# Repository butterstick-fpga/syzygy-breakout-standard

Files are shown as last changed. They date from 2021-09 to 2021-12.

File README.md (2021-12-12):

# SYZYGY breakout

SYZYGY is an FPGA expansion standard for medium to high speed interfaces. Learn more and check out the specifications here: [https://syzygyfpga.io/](https://syzygyfpga.io/)

> Note that the attiny44A populated on boards from the GroupGets campaign are delivered blank.

---

## What is it

- A breakout with all 32 I/O pins broken out to a 0.1" header. 
- A small prototyping area is also provided.
- attiny44a provided to enable SYZYGY DNA features.

## Photos

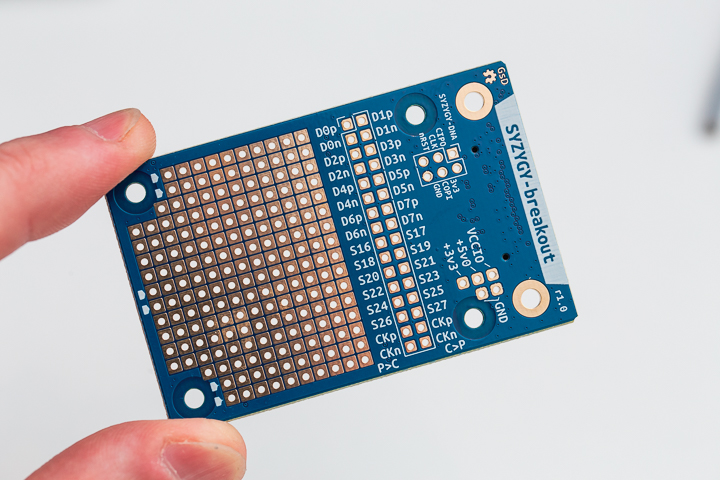
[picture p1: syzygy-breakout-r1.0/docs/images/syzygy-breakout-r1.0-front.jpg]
Front
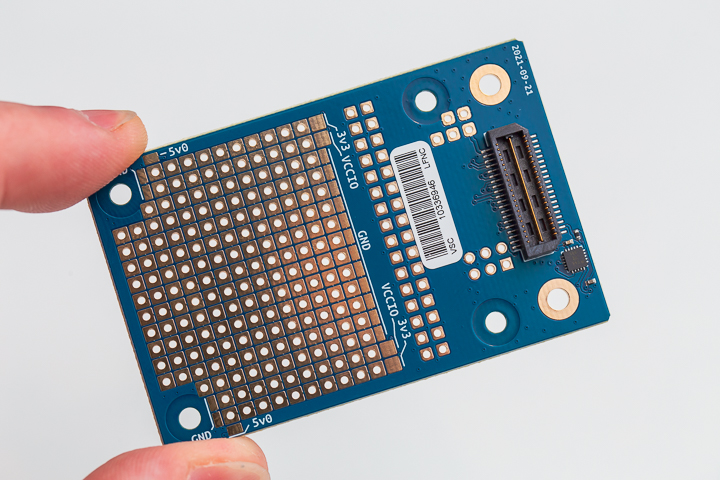
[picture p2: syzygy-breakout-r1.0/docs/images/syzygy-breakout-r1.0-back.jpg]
Back
 

## Prototyping area

The prototyping area is set up like a traditional breadboard layout, if you examine the back of the board you can see tracks that run between the 0.1" prototyping holes.
You can also see these details in the KiCad design files.

Available on the back of the board is various power rails that are available to "jumper" across to the prototyping area.

## Attiny44A Firmware

The attiny44A is fitted to provide SYZYGY DNA features, a mechanism that SYZYGY controllers can poll to determine what pods are connected, and their VCCIO range etc.

Currently, the firmware for this hasn't been developed/tested yet. This feature also requires the controller (E.g. ButterStick) to have a mechanism to poll the pods for this info.

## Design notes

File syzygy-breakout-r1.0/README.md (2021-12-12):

# SYZYGY breakout

SYZYGY is an FPGA expansion standard for medium to high speed interfaces. Learn more and check out the specifications here: [https://syzygyfpga.io/](https://syzygyfpga.io/)

---

## What is it

A breakout with all 32 I/O pins broken out to a 0.1" header. 

A small prototyping area is also provided.

## Folder structure

```
kicad-src: KiCad v6 source files
production:
 - Gerbers:      [project]_gerbers.zip
 - Schematic:    [project].pdf
 - Board render: [project].png
```

## Photos

Front Back

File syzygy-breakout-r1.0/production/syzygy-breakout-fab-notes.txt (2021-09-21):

Part number:        syzygy-breakout-r1.0

General fabrication notes

    * Board material is S1000-2
    * Blue solder mask on both sides of board. All vias to be tented.
    * White LPI legend on both sides of board.
    * Pad finish is ENIG.
    * Finished board thickness is 1.6 mm
    * Broads in panel. Arrangement TBD, using routing/tabs/v-score.
    
Suggested stackup
    1   35 μm (1 oz) copper         Signal
        0.2mm prepreg
    2   17 μm (0.5 oz) copper       Signal
        Select core/prepreg for final board thickness
    3   17 μm (0.5 oz) copper       Ground
        0.2mm prepreg
    4   35 μm (1 oz) copper         Signal

File naming
    syzygy-breakout-Edge_Cuts.gbr        Board outline
    syzygy-breakout-PTH.drl              Through-board plated holes
    syzygy-breakout-NPTH.drl             Through-board unplated holes
    syzygy-breakout-F_SilkS.gbr          Front silkscreen
    syzygy-breakout-F_Mask.gbr           Front solder mask
    syzygy-breakout-F_Cu.gbr             Layer 1 copper (Front)
    syzygy-breakout-In1_Cu.gbr           Layer 2 copper
    syzygy-breakout-In2_Cu.gbr           Layer 3 copper
    syzygy-breakout-B_Cu.gbr             Layer 4 copper (Back)
    syzygy-breakout-B_Mask.gbr           Back solder mask
    syzygy-breakout-B_SilkS.gbr          Back silkscreen

    syzygy-breakout-PTH-drl_map.pdf      Drill Map Reference plated
    syzygy-breakout-NPTH-drl_map.pdf     Drill Map Reference non-plated

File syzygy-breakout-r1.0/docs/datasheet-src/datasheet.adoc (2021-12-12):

= SYZYGY Pod
:imagesdir: ../images
:source-highlighter: rouge
:bl: pass:[ +]
:toc: macro
:icons: font

_Standard Breakout_

'''

== General Description
The SYZYGY Standard Breakout is an addon board for carriers following the SYZYGY FPGA standard.

The POD features the SYZYGY Stardard connector that enables 32 single ended I/O or 10 differential pairs. It also features a small ATTiny44 microcontroller, that can be used to implement SYZYGY-DNA features.

All SYZYGY I/O signals are routed into a 0.1" labeled dual-row header, From here connections can be made directly or jumped over onto the prototyping area on the PCB. Breakouts are also offered for the ATTiny ICSP interface, and voltages from the carrier.

'''

[cols=2,frame=none,grid=none]
|===
a|
[#_anchor]
== Key features:
  * Compact Size
  * All I/O broken out
  * Universial prototyping area

SYZYGY Breakout Front

a|
== Specifications:
  * All 32 SYZYGY-STD I/O broken out
  * All power rail broken out
  * Multiple power configurations
  * SYZYGY-DNA I2C bus accessable
  * Lots of prototyping space
  * Open source KiCad Design
  * Dimensions: 45.0mm x 70.0mm (1.8" x 2.8")
|===

{bl}
{bl}

== Product Variants

[cols="1,2",frame=ends, grid=cols]
|===
|Part Number|Description

|SYZYGY-STD-R1D0
|Populated PCBA, unprogrammed.

|SYZYGY-STD-R1D0-BARE
|Bare PCB

|===

<<<

== Licence
 - Hardware: https://spdx.org/licenses/CERN-OHL-P-2.0.html[CERN-OHL-P-2.0]
 - Documentation: https://spdx.org/licenses/CC-BY-SA-4.0.html[CC-BY-SA-4.0]

{bl}
{bl}

== Revision History

[cols="^1,^1,6",frame=ends, grid=cols]
|===
|Revision|Date|Description

|r1d0|2021-12-12|Initial Release

|===

{bl}
{bl}

toc::[]

<<<

== Images

.Top of PCB
SYZYGY Breakout Front

.Bottom Of PCB 
[SYZYGY Breakout Back

<<<

{bl}

== Pinout

[cols="^1,2,^1,2",width=50%,align=center,frame=all, grid=cols, stripes=even]
|===
|Pin|Signal Name|Pin|Signal Name

|`1`  | `S0 D0p`  |  `2`  | `S1 D1p`
|`3`  | `S2 D0n`  |  `4`  | `S3 D1n`
|`5`  | `S4 D2p`  |  `6`  | `S5 D3p`
|`7`  | `S6 D2n`  |  `8`  | `S7 D3n`
|`9`  | `S8 D4p`  |  `10` | `S9 D5p`
|`11` | `S10 D4n` |  `12` | `S11 D5n` 
|`13` | `S12 D6p` |  `14` | `S13 D7p` 
|`15` | `S14 D6n` |  `16` | `S15 D7n` 
|`17` | `S16`     |  `18` | `S17` 
|`19` | `S18`     |  `20` | `S19` 
|`21` | `S20`     |  `22` | `S21` 
|`23` | `S22`     |  `24` | `S23` 
|`25` | `S24`     |  `26` | `S25` 
|`27` | `S26`     |  `28` | `S27` 
|`29` | `P2C CLKp` |  `30` | `C2P CLKp` 
|`31` | `P2C CLKn` |  `32` | `C2P CLKn` 
|===

{bl}

.Signal Descriptions
[cols="^1,^1,4",frame=all, grid=cols, stripes=even,separator=%]
|===
%Signal Name % Direction % Description

%D[0,2,4,6]{P|N}  % Input  % Differential I/O
%D[1,3,5,7]{P|N}  % Output % Differential I/O
%S[27:0]      % BIDIR  % Single-ended I/O
%P2C_CLK{P|N} % P2C    % Differential clock pair provided by pod to carrier. Where possible, these signals should connect to a dedicated clock input on the host.
%C2P_CLK{P|N} % C2P    % Differential clock pair provided by carrier to pod
|===

<<<

== SYZYGY DNA

The embedded ATTiny44a can be used to implement the SYZYGY-DNA feature of the specification. A through hole footprint is provided to facilitate programming and debug.

.SYZYGY-DNA program/debug connector
[cols="^1,2,^1,2",width=50%,frame=all, grid=cols, stripes=even]
|===
|Pin|Signal Name|Pin|Signal Name

|`1`  | `CIPO`       |  `2`  | `3v3`
|`3`  | `CLK / SCL`  |  `4`  | `COPI / SDA`
|`5`  | `nRST`       |  `6`  | `GND`
|===

== Prototyping area

[TIP]
Prototyping areas is connected together in an arrangement much like a typical breadboard, a sharp exacto/scapel can be used to cut connection from the back of the PCB

<<<



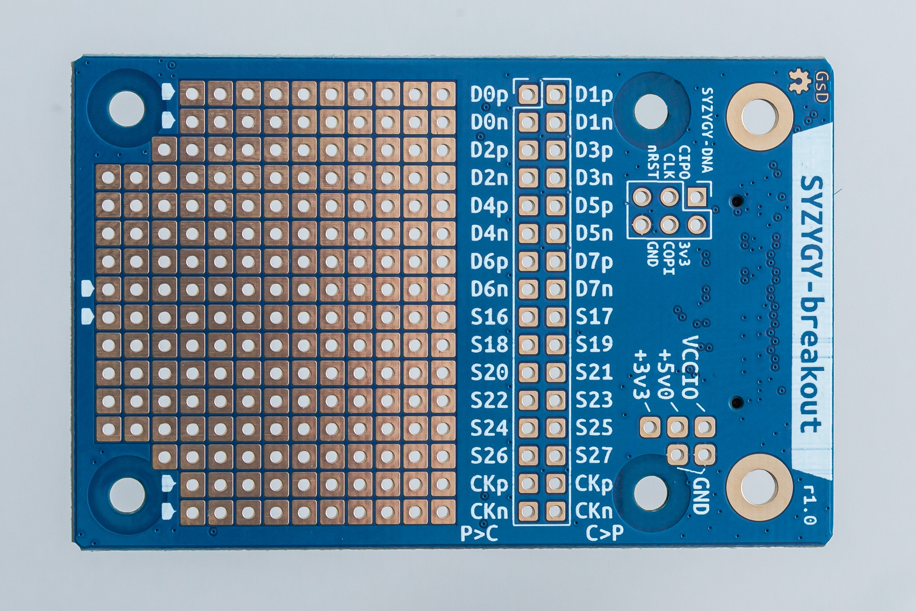
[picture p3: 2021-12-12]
syzygy-breakout-r1.0/docs/images/full-res/syzygy-breakout-r1.0-front-1.jpg

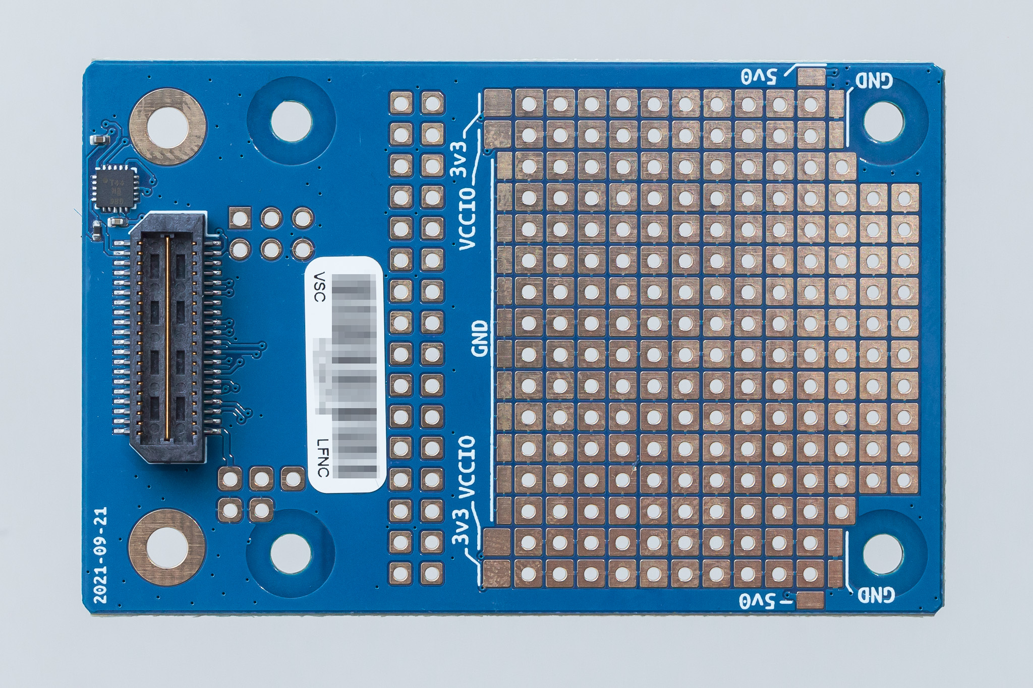
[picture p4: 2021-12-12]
syzygy-breakout-r1.0/docs/images/full-res/syzygy-breakout-r1.0-back-1.jpg

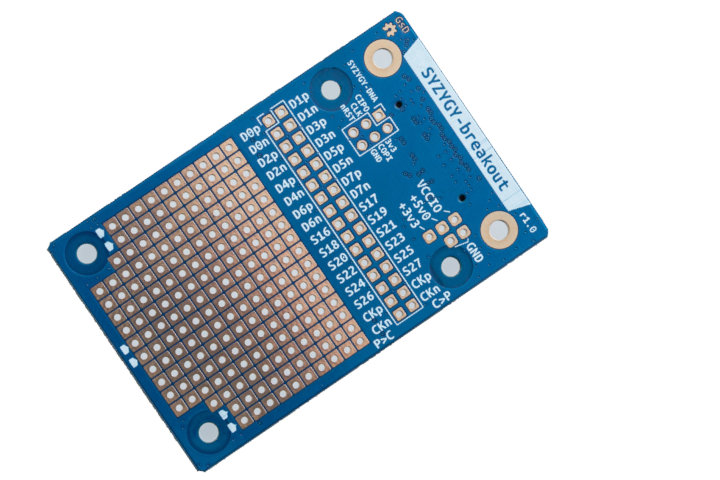
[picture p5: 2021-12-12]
syzygy-breakout-r1.0/docs/images/syzygy-breakout-r1.0-front-2.jpg

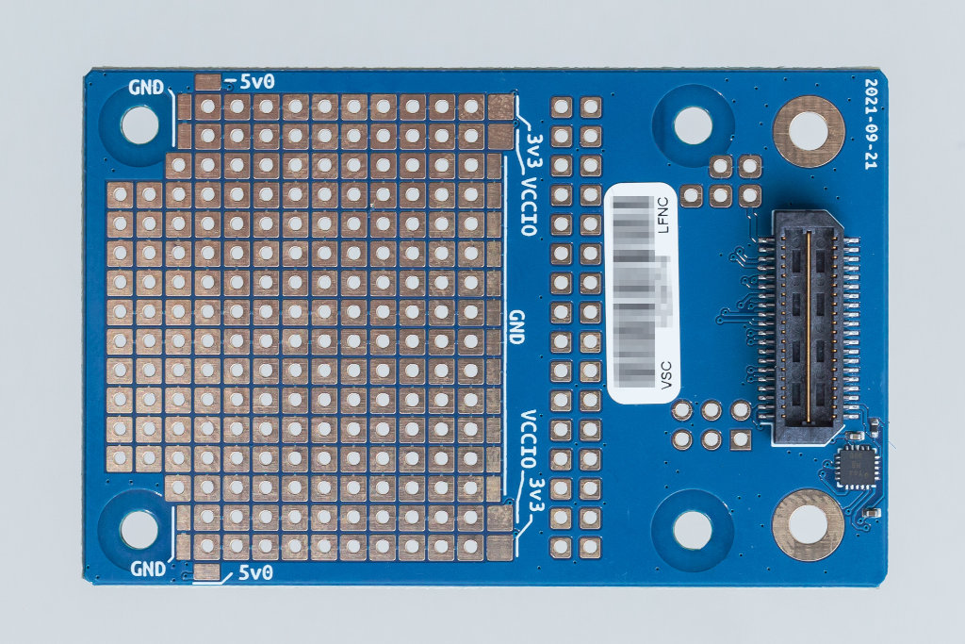
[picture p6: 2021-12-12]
syzygy-breakout-r1.0/docs/images/syzygy-breakout-r1.0-back-1.jpg

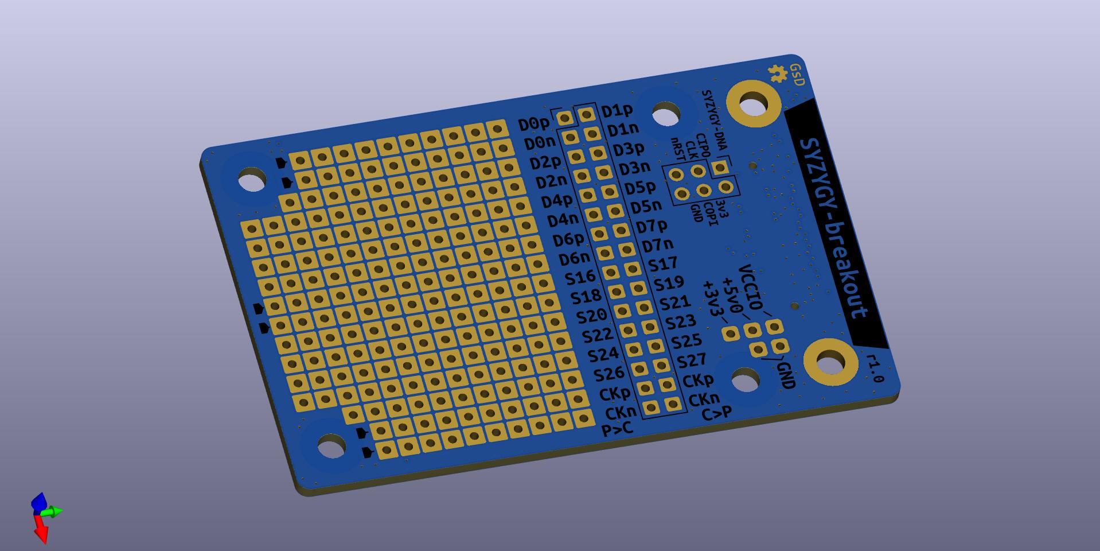
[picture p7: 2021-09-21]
syzygy-breakout-r1.0/production/syzygy-breakout.jpg

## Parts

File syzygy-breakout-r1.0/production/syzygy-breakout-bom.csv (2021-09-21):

Source: | /home/greg/Projects/butterstick-fpga/syzygy-breakout-standard/syzygy-breakout-r1.0/kicad-src/syzygy-breakout.kicad_sch
Date: | Tue 21 Sep 2021 11:58:37
Tool: | Eeschema 5.99.0-unknown-34c2bd58d1~131~ubuntu21.04.1
Generator: | /usr/share/kicad-nightly/plugins/bom_csv_grouped_by_value.py
Component Count: | 5
Individual Components:
Item | Qty | Reference(s) | Value | LibPart | Footprint | Datasheet | Mfg | PN
 |  | C9 | 0.1uF | Device:C | Capacitor_SMD:C_0402_1005Metric |  | Samsung Electro-Mechanics | CL05B104KP5NNNC
 |  | C10 | 1uF | Device:C | Capacitor_SMD:C_0402_1005Metric |  | Samsung Electro-Mechanics | CL05A105KP5NNNC
 |  | J1 | SYZYGY-STD | gsd-kicad:SYZYGY-STD | gsd-footprints:SYZYGY-STD-POD |  | Samtec Inc. | QTE-020-01-F-D-A-K-TR
 |  | R15 | 10K | Device:R | Resistor_SMD:R_0402_1005Metric |  | Stackpole Electronics Inc | RMCF0402FT10K0
 |  | U2 | ATtiny44A-MMH | SyzygyLVDSPod-rescue:ATtiny44A-MMH-MCU_Microchip_ATtiny | Package_DFN_QFN:QFN-20-1EP_3x3mm_P0.45mm_EP1.6x1.6mm | http://ww1.microchip.com/downloads/en/DeviceDoc/doc8183.pdf | Microchip Technology | ATTINY44A-MMH
Collated Components:
Item | Qty | Reference(s) | Value | LibPart | Footprint | Datasheet | Mfg | PN
1 | 1 | C9 | 0.1uF | Device:C | Capacitor_SMD:C_0402_1005Metric |  | Samsung Electro-Mechanics | CL05B104KP5NNNC
2 | 1 | C10 | 1uF | Device:C | Capacitor_SMD:C_0402_1005Metric |  | Samsung Electro-Mechanics | CL05A105KP5NNNC
3 | 1 | J1 | SYZYGY-STD | gsd-kicad:SYZYGY-STD | gsd-footprints:SYZYGY-STD-POD |  | Samtec Inc. | QTE-020-01-F-D-A-K-TR
4 | 1 | R15 | 10K | Device:R | Resistor_SMD:R_0402_1005Metric |  | Stackpole Electronics Inc | RMCF0402FT10K0
5 | 1 | U2 | ATtiny44A-MMH | SyzygyLVDSPod-rescue:ATtiny44A-MMH-MCU_Microchip_ATtiny | Package_DFN_QFN:QFN-20-1EP_3x3mm_P0.45mm_EP1.6x1.6mm | http://ww1.microchip.com/downloads/en/DeviceDoc/doc8183.pdf | Microchip Technology | ATTINY44A-MMH

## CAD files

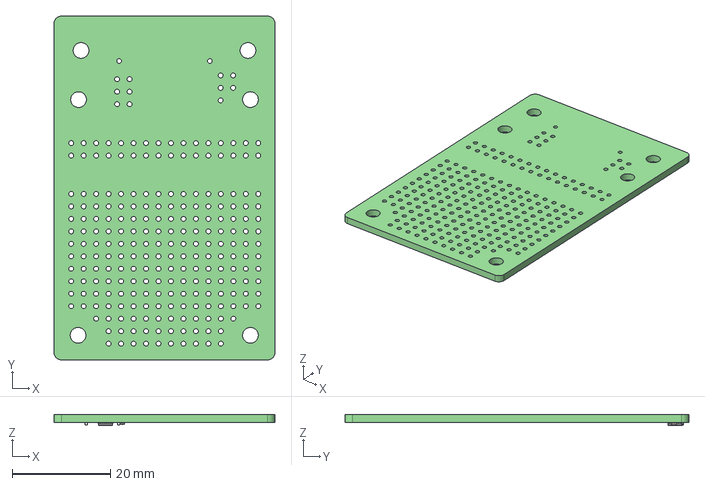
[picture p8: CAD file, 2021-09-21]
syzygy-breakout-r1.0/production/syzygy-breakout.step
45.0 x 70.0 x 2.25 mm
syzygy-breakout PCB

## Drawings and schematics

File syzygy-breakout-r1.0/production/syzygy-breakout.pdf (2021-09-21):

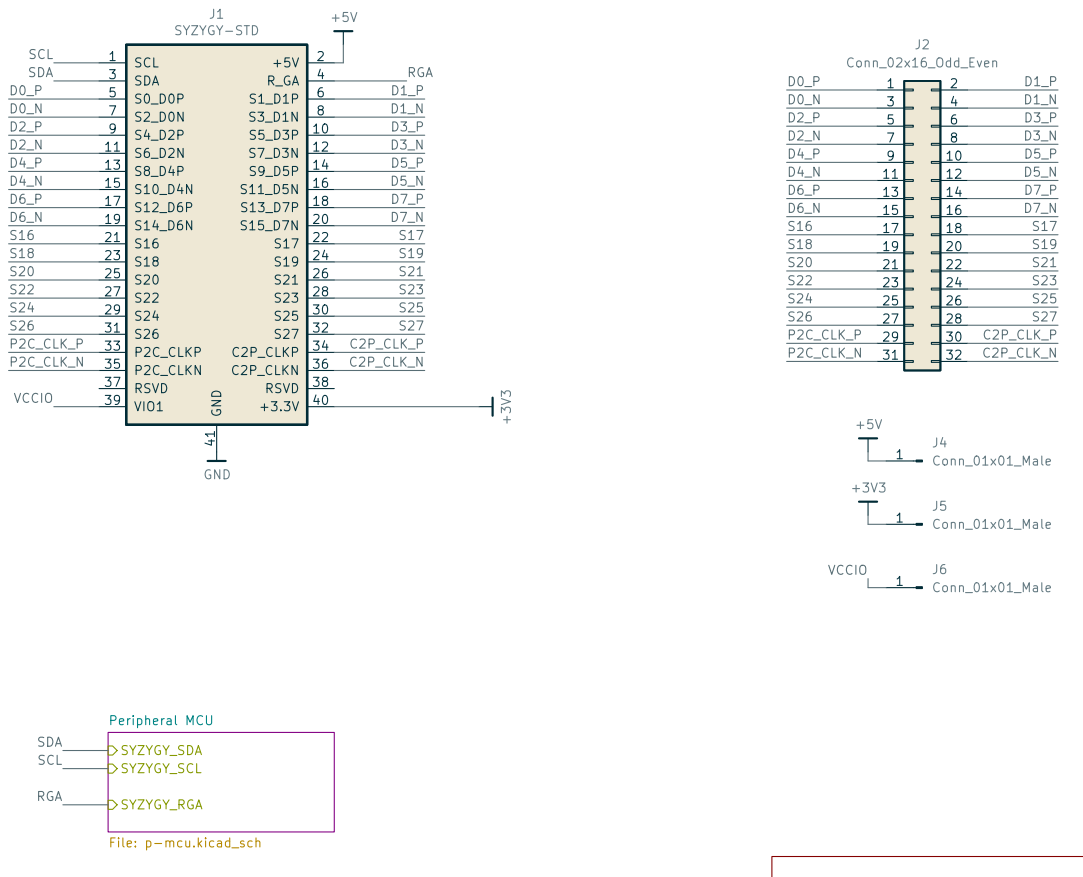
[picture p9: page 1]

Peripheral MCU
File: syzygy-breakout.kicad_sch Sheet: / GsD - @gregdavill SYZYGY Pod SYZYGY_SCL SYZYGY_SDA

Id: 1/2 Title: SYZYGY Breakout

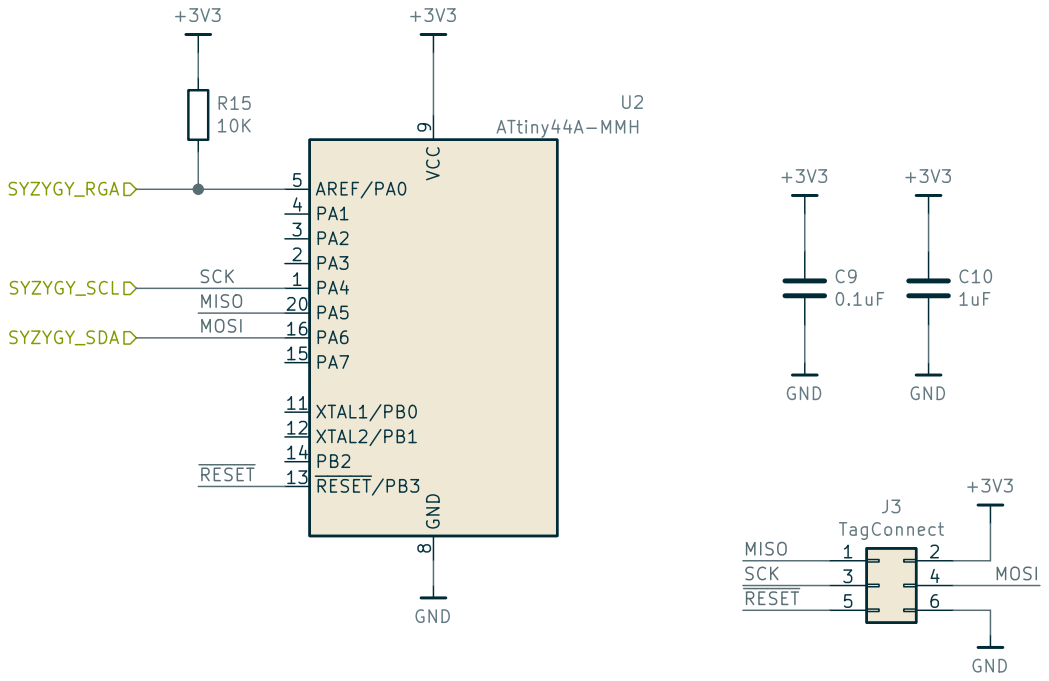
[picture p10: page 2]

Sheet: /Peripheral MCU/
File: p-mcu.kicad_sch
Id: 2/2 Title: SYZYGY Breakout

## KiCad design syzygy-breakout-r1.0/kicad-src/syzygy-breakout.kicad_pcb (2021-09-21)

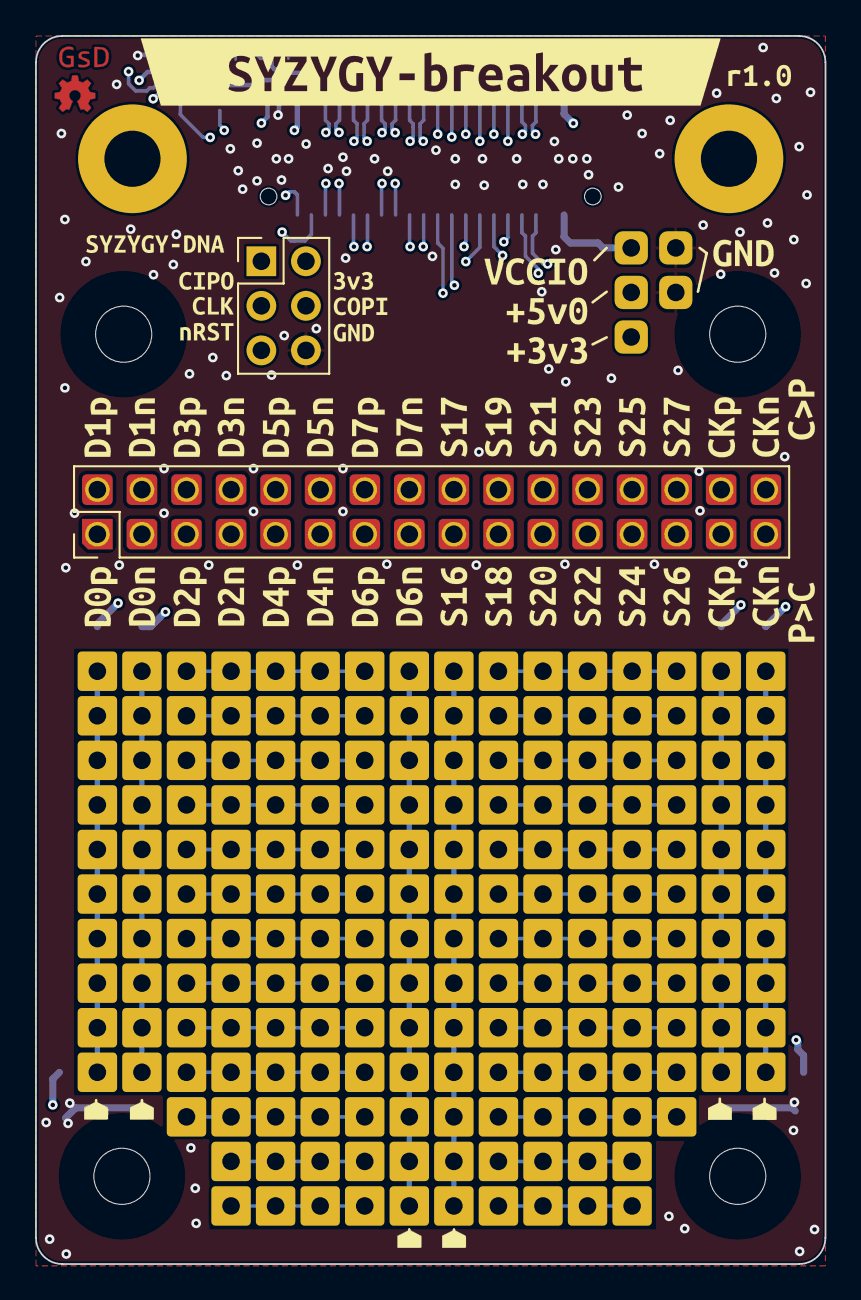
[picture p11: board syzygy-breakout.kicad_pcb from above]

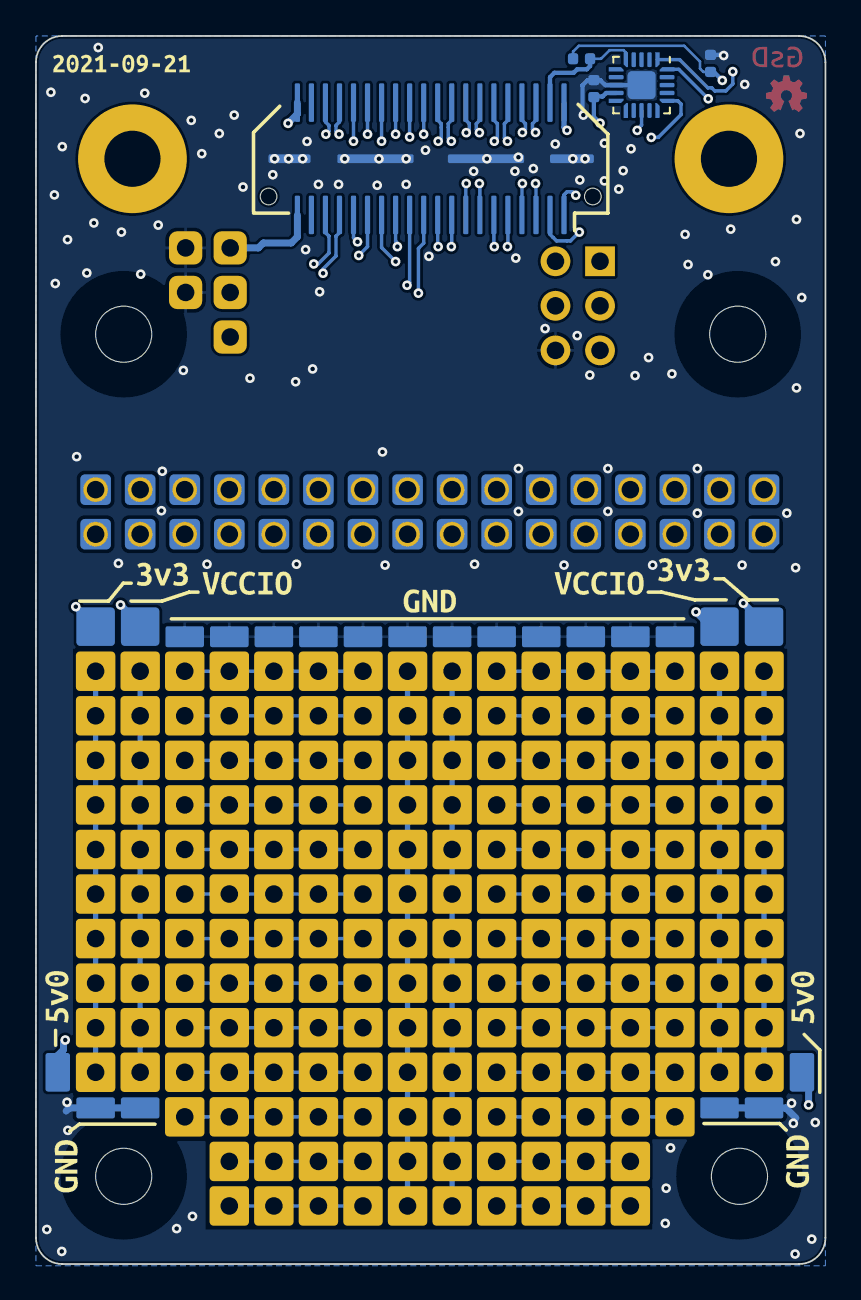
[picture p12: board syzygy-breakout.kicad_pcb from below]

Board: 4 copper layers, 45.0 x 70.0 mm, 73 parts (15 on the bottom side), 41 nets.

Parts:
C9: 0.1uF; C_0402_1005Metric
C10: 1uF; C_0402_1005Metric
H1, H2, H3, H4: MountingHole; MountingHole_3.2mm_M3_DIN965
J1: SYZYGY-STD; SYZYGY-STD-POD
J2: Conn_02x16_Odd_Even; PinHeader_2x16_P2.54mm_Vertical
J3: TagConnect; PinHeader_2x03_P2.54mm_Vertical
J4, J4#2, J5, J6, J6#2: Conn_01x01_Male; PinHeader_1x01_P2.54mm_Vertical
R15: 10K; R_0402_1005Metric
U2: ATtiny44A-MMH; QFN-20-1EP_3x3mm_P0.45mm_EP1.6x1.6mm
kibuzzard-61491A46, kibuzzard-61491A46#2: G***; kibuzzard-61491A46
kibuzzard-61491AB0, kibuzzard-61491AB0#2: G***; kibuzzard-61491AB0
kibuzzard-61491ABE, kibuzzard-61491ABE#2: G***; kibuzzard-61491ABE
kibuzzard-61491FCC: G***; kibuzzard-61491FCC
kibuzzard-61492D1E: G***; kibuzzard-61492D1E
kibuzzard-61492D2E: G***; kibuzzard-61492D2E
kibuzzard-61492D9C: G***; kibuzzard-61492D9C
kibuzzard-61492D24: G***; kibuzzard-61492D24
kibuzzard-614919EA, kibuzzard-614919EA#2, kibuzzard-614919EA#3: G***; kibuzzard-614919EA
kibuzzard-614928B5: G***; kibuzzard-614928B5
kibuzzard-614928DD: G***; kibuzzard-614928DD
kibuzzard-614928EC: G***; kibuzzard-614928EC
kibuzzard-614928F9: G***; kibuzzard-614928F9
kibuzzard-614937C5: G***; kibuzzard-614937C5
kibuzzard-614937CF: G***; kibuzzard-614937CF
kibuzzard-614937D4: G***; kibuzzard-614937D4
kibuzzard-614937D9: G***; kibuzzard-614937D9
kibuzzard-614937DF: G***; kibuzzard-614937DF
kibuzzard-614937E3: G***; kibuzzard-614937E3
kibuzzard-614937E9: G***; kibuzzard-614937E9
kibuzzard-614937EE: G***; kibuzzard-614937EE
kibuzzard-614937F3: G***; kibuzzard-614937F3
kibuzzard-614937F8: G***; kibuzzard-614937F8
kibuzzard-614937FC: G***; kibuzzard-614937FC
kibuzzard-6149253E: G***; kibuzzard-6149253E
kibuzzard-6149290C: G***; kibuzzard-6149290C
kibuzzard-6149371A: G***; kibuzzard-6149371A
kibuzzard-6149372C: G***; kibuzzard-6149372C
kibuzzard-6149373C: G***; kibuzzard-6149373C
kibuzzard-6149374B: G***; kibuzzard-6149374B
kibuzzard-6149374F: G***; kibuzzard-6149374F
kibuzzard-6149375A: G***; kibuzzard-6149375A
kibuzzard-6149375F: G***; kibuzzard-6149375F
kibuzzard-6149380F, kibuzzard-6149380F#2: G***; kibuzzard-6149380F
kibuzzard-6149386B: G***; kibuzzard-6149386B
kibuzzard-61492572: G***; kibuzzard-61492572
kibuzzard-61492903: G***; kibuzzard-61492903
kibuzzard-61492915: G***; kibuzzard-61492915
kibuzzard-61493714: G***; kibuzzard-61493714
kibuzzard-61493721: G***; kibuzzard-61493721
kibuzzard-61493726: G***; kibuzzard-61493726
kibuzzard-61493731: G***; kibuzzard-61493731
kibuzzard-61493737: G***; kibuzzard-61493737
kibuzzard-61493742: G***; kibuzzard-61493742
kibuzzard-61493746: G***; kibuzzard-61493746
kibuzzard-61493754: G***; kibuzzard-61493754
kibuzzard-61493763: G***; kibuzzard-61493763
kibuzzard-61493801: G***; kibuzzard-61493801
kibuzzard-61493817, kibuzzard-61493817#2: G***; kibuzzard-61493817
kibuzzard-61493858: G***; kibuzzard-61493858

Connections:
+3V3: C9.1, C10.1, J1.40 (+3.3V), J3.2, J5.1, R15.1, U2.9 (VCC)
+5V: J1.2 (+5V), J4#2.1
/C2P_CLK_N: J1.36 (C2P_CLKN), J2.32
/C2P_CLK_P: J1.34 (C2P_CLKP), J2.30
/D0_N: J1.7 (S2_D0N), J2.3
/D0_P: J1.5 (S0_D0P), J2.1
/D1_N: J1.8 (S3_D1N), J2.4
/D1_P: J1.6 (S1_D1P), J2.2
/D2_N: J1.11 (S6_D2N), J2.7
/D2_P: J1.9 (S4_D2P), J2.5
/D3_N: J1.12 (S7_D3N), J2.8
/D3_P: J1.10 (S5_D3P), J2.6
/D4_N: J1.15 (S10_D4N), J2.11
/D4_P: J1.13 (S8_D4P), J2.9
/D5_N: J1.16 (S11_D5N), J2.12
/D5_P: J1.14 (S9_D5P), J2.10
/D6_N: J1.19 (S14_D6N), J2.15
/D6_P: J1.17 (S12_D6P), J2.13
/D7_N: J1.20 (S15_D7N), J2.16
/D7_P: J1.18 (S13_D7P), J2.14
/P2C_CLK_N: J1.35 (P2C_CLKN), J2.31
/P2C_CLK_P: J1.33 (P2C_CLKP), J2.29
/Peripheral MCU/MISO: J3.1, U2.20 (PA5)
/Peripheral MCU/~RESET: J3.5, U2.13 (~RESET~/PB3)
/RGA: J1.4 (R_GA), R15.2, U2.5 (AREF/PA0)
/S16: J1.21 (S16), J2.17
/S17: J1.22 (S17), J2.18
/S18: J1.23 (S18), J2.19
/S19: J1.24 (S19), J2.20
/S20: J1.25 (S20), J2.21
/S21: J1.26 (S21), J2.22
/S22: J1.27 (S22), J2.23
/S23: J1.28 (S23), J2.24
/S24: J1.29 (S24), J2.25
/S25: J1.30 (S25), J2.26
/S26: J1.31 (S26), J2.27
/S27: J1.32 (S27), J2.28
/SCL: J1.1 (SCL), J3.3, U2.1 (PA4)
/SDA: J1.3 (SDA), J3.4, U2.16 (PA6)
/VCCIO: J1.39 (VIO1), J6.1
GND: C9.2, C10.2, J1.41 (GND), J3.6, J4.1, J6#2.1, U2.8 (GND), U2.21 (GND)

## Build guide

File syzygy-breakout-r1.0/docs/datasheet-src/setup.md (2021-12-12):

Setup steps

```console
$ bash --login
$ rvm use 2.7.2
$ bash build_docs.sh
```

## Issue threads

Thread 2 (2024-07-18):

Doc: Add diagram of prototyping area

gregdavill, 2024-07-18:
# Initial query
From `TheZoq2` via discord
> I had a bunch of random shorts between pads on my syzygy breakout board. They all seem to be on the bottom, and cutting between the pads with a knife fixed them

# Issue
The prototyping area is designed to resemble a breadboard layout, and as a result has connection between the pads.

The only place this is documented right now is in the KiCad source files.

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

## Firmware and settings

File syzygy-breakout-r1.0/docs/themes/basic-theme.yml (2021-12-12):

font:
  catalog:
    # Noto Serif supports Latin, Latin-1 Supplement, Latin Extended-A, Greek, Cyrillic, Vietnamese & an assortment of symbols
    Noto Serif:
      normal: GEM_FONTS_DIR/notoserif-regular-subset.ttf
      bold: GEM_FONTS_DIR/notoserif-bold-subset.ttf
      italic: GEM_FONTS_DIR/notoserif-italic-subset.ttf
      bold_italic: GEM_FONTS_DIR/notoserif-bold_italic-subset.ttf
    # M+ 1mn supports ASCII and the circled numbers used for conums
    M+ 1mn:
      normal: GEM_FONTS_DIR/mplus1mn-regular-subset.ttf
      bold: GEM_FONTS_DIR/mplus1mn-bold-subset.ttf
      italic: GEM_FONTS_DIR/mplus1mn-italic-subset.ttf
      bold_italic: GEM_FONTS_DIR/mplus1mn-bold_italic-subset.ttf
page:
  background_color: FFFFFF
  layout: portrait
  initial_zoom: FitH
  margin: [0.5in, 0.67in, 0.67in, 0.67in]
  # margin_inner and margin_outer keys are used for recto/verso print margins when media=prepress
  margin_inner: 0.75in
  margin_outer: 0.59in
  size: A4
  background-image:
    fit: contain
base:
  align: left
  # color as hex string (leading # is optional)
  font_color: 333333
  # color as RGB array
  #font_color: [51, 51, 51]
  # color as CMYK array (approximated)
  #font_color: [0, 0, 0, 0.92]
  #font_color: [0, 0, 0, 92%]
  font_family: Noto Serif
  # choose one of these font_size/line_height_length combinations
  #font_size: 14
  #line_height_length: 20
  #font_size: 11.25
  #line_height_length: 18
  #font_size: 11.2
  #line_height_length: 16
  font_size: 10
  #line_height_length: 15
  # correct line height for Noto Serif metrics
  line_height_length: 12
  #font_size: 11.25
  #line_height_length: 18
  line_height: $base_line_height_length / $base_font_size
  font_size_large: round($base_font_size * 1.25)
  font_size_small: round($base_font_size * 0.85)
  font_size_min: $base_font_size * 0.75
  font_style: normal
  border_color: EEEEEE
  border_radius: 4
  border_width: 0.5
title:
  align: left
role:
  line-through:
    text_decoration: line-through
  underline:
    text_decoration: underline
  big:
    font_size: $base_font_size_large
  small:
    font_size: $base_font_size_small
  subtitle:
    font_color: 999999
    font_size: 0.8em
    font_style: normal_italic
# FIXME vertical_rhythm is weird; we should think in terms of ems
#vertical_rhythm: $base_line_height_length * 2 / 3
# correct line height for Noto Serif metrics (comes with built-in line height)
vertical_rhythm: $base_line_height_length
horizontal_rhythm: $base_line_height_length
link:
  font_color: 428BCA
# literal is currently used for inline monospaced in prose and table cells
literal:
  font_color: B12146
  font_family: M+ 1mn
button:
  content: "[\u2009%s\u2009]"
  font_style: bold
key:
  background_color: F5F5F5
  border_color: CCCCCC
  border_offset: 2
  border_radius: 2
  border_width: 0.5
  font_family: $literal_font_family
  separator: "\u202f+\u202f"
mark:
  background_color: FFFF00
  border_offset: 1
menu:
  caret_content: " <font size=\"1.15em\" color=\"#B12146\">\u203a</font> "
heading:
  align: left
  font_color: $base_font_color
  font_style: bold
  # h1 is used for part titles (book doctype) or the doctitle (article doctype)
  h1:
    font_size: floor($base_font_size * 2.6)
    margin_bottom: $vertical_rhythm * 0.1
    align: left
  # h2 is used for chapter titles (book doctype only)
  h2:
    font_size: floor($base_font_size * 1.5)
    margin_bottom: $vertical_rhythm * 0.2
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
